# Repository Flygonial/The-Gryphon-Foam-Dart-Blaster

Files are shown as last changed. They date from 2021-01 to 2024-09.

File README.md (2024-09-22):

# The-Gryphon-Foam-Dart-Blaster
The Gryphon is a mostly 3D printable, hobby-grade, Nerf semi-automatic flywheel blaster. Its main design features are as follows:

* Uses 130 to 180 sized 20.4mm , brushed DC motors.
* Semi-auto by rack and pinion with 1:3 gear multiplication. The trigger pull is fairly short at 12mm.
* Accepts 33 to 38mm OD flywheels (all 2mm shaft fit, superstock upgrade flywheels).
* Utilizes a horizontal flywheel cage that bolts directly onto the magwell. This is a mounting pattern less prone to misalignment than a Stryfe's mounting bosses or similar.
* Accepts Worker Talon mags, Katana-geometry mags with a lower release cut-out, and almost all full-length magazines.
* Battery is located in the stock or a side battery tray.
* Full-length feed guide integrated in magwell for maximum feeding reliability.
* Bore-axis is almost as close as possible to top rail of blaster, which is theoretically more intuitive to aim with.
* Will fit on build volume as small as 120 mm<sup>3</sup>.

Some options/variable features are:

* Variable motor center distances from 43.5mm to 38.5mm (Eclipse).
* Full-length, flat-top picatinny rail.
* Ambidextrous, or one-sided sling mounts, or a WORKER attachable sling mount.
* A mag release meant to be actuated by the operator's off-hand, and one meant for the dominant hand's middle finger.
* Flash hider: Helps work around cover, and can be used to house and launch a mega dart.
* Kill-switch mount on stock, and a kill-switch + voltmeter mount on stock, and variations for imperial PVC using 3/4'' PVC instead of 25mm PVC.
* An additional EXPD stock option that holds larger batteries, has the same options.
* 14mm or 14.5mm bore flywheel cages or MAX cages, which are 15mm bore, Daybreak / Twilight only, have extra motor can support, and are intended for maximum FPS.
* An optional foregrip and magwell option for mounting this foregrip.
* An optional bottom-picatinny variant of the motor cover.
* 2-stage flywheel cages in all the aforementioned 'crushes' and bore options.
* Talon, 'Kathanha/Katobu', and full-length magwell options.

Required for assembly:

* Two 130-180 sized motors.
* 33 to 38mm, 2mm shaft fit flywheels
* 16-18 AWG multi-strand hobby wire
* Connectors of choice (XT60, Deans, bullet connectors), and heat shrink.
* One full-sized microswitch, 15A or 21A.
* M3 nuts
* M3 screws: 5mm length, 8mm length, 10mm length, one 14-16mm length for mag release pivot, one 20mm length for one specific screw on the motor cover.
* M2 screws: 4-5mm length for motor mounting.
* 2x20mm steel dowel pin for the pinion gear.
* 0.5mm coil thickness, 5mm diameter compression springs. 15mm in length for the mag release, 50mm in length for the trigger return spring.
* An adhesive for stock assembly, preferably methyl methacrylate based.
* Modular connectors to flywheel cage and to stock assembly (if using kill switch and/or voltmeter) highly recommended.
* For a battery stock: 10-20cm length of 25mm OD PVC pipe (length depends on however long you want your stock), or 3/4' Sch 40 PVC.

# Licensed under the CC0 1.0 Universal Public Domain Dedication (Creative Commons) license.

Do whatever you please with this blaster, modify, distribute, sell. Preferably don't claim ownership of the original design, that'd be all I want.

The main CAD files are bigger than 25 MB and have stopped playing nice with GitHub, so the most up to date source files at any time are available here: https://a360.co/4bTqc8o

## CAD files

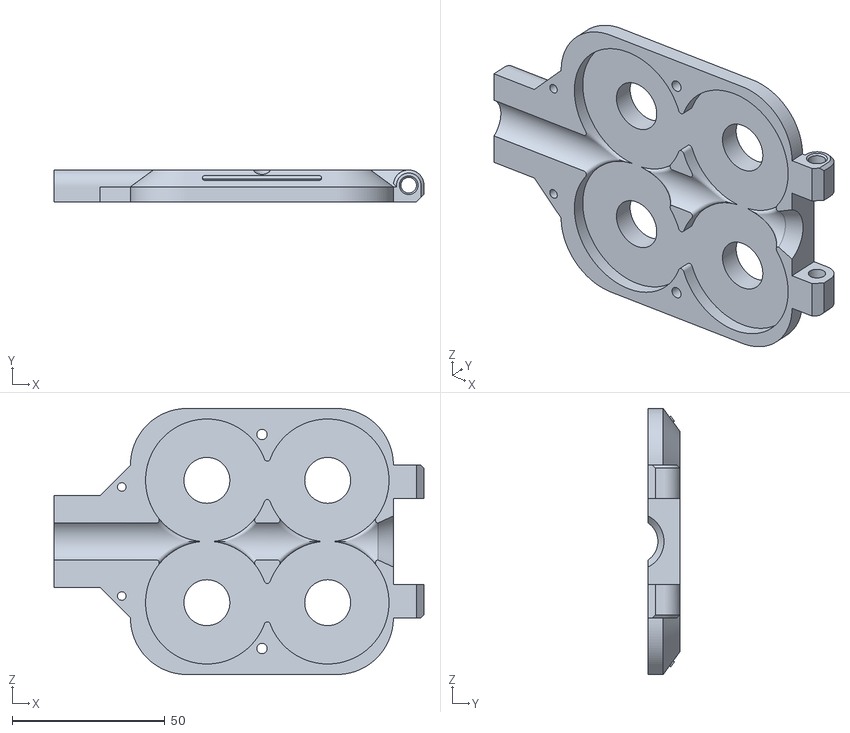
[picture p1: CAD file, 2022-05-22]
Gryphon Takedown/14.5mm Bore/2S 14.5mm Bore TKD/2S 40mm TKD (14.5)/2S 40mm FW Cover (14.5).stl
121.0 x 10.5 x 87.0

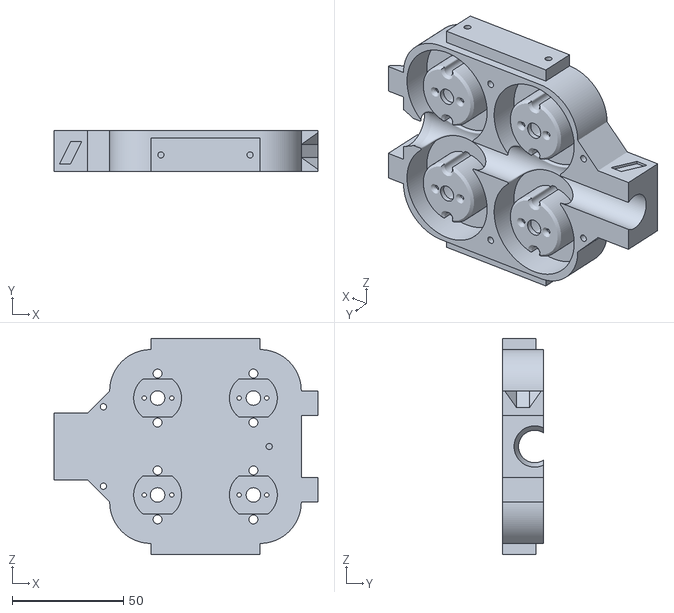
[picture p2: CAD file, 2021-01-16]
Gryphon Takedown/14.5mm Bore/2S 14.5mm Bore TKD/2S 43.5mm FWC TKD (14.5)/2S 43.5mm FWC TKD (14.5).stl
118.5 x 18.5 x 97.0

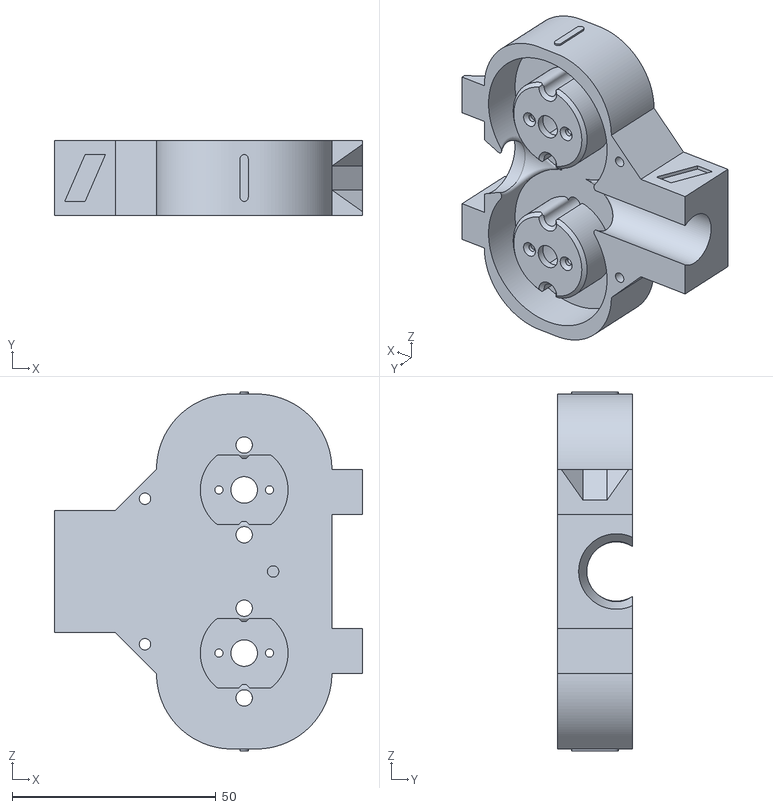
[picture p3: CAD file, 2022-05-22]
Gryphon Takedown/14.5mm Bore/40mm TKD (14.5)/40mm FWC TKD (14.5).stl
75.5 x 18.5 x 88.0

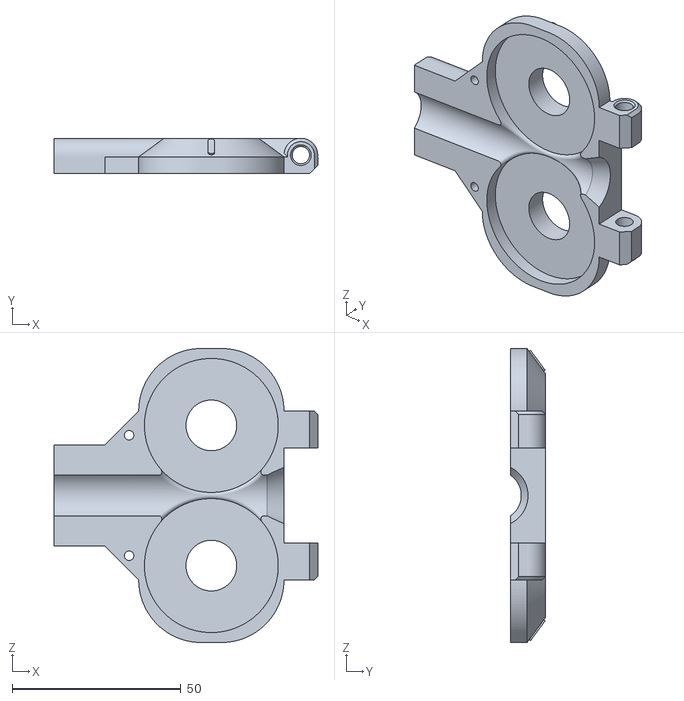
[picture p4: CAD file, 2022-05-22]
Gryphon Takedown/14.5mm Bore/41.5mm TKD (14.5)/41.5mm FW Cover TKD (14.5).stl
78.0 x 10.5 x 87.0

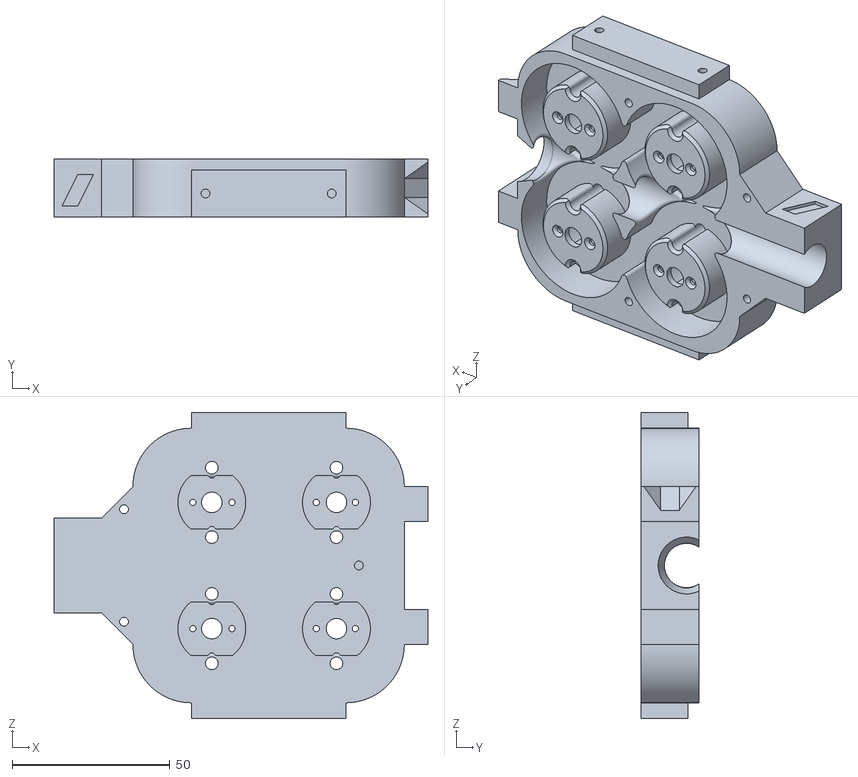
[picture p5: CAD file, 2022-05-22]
Gryphon Takedown/14mm Bore/2S 14mm Bore TKD/2S 40mm TKD/2S 40mm FWC TKD.stl
118.5 x 18.5 x 97.0

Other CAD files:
Gryphon Takedown/14.5mm Bore/2S 14.5mm Bore TKD/2S 41.5mm TKD (14.5)/2S 41.5mm FWC TKD (14.5).stl
Gryphon Takedown/14.5mm Bore/2S 14.5mm Bore TKD/2S 41mm TKD (14.5)/2S 41mm FW Cover TKD (14.5).stl
Gryphon Takedown/14.5mm Bore/2S 14.5mm Bore TKD/2S 42.5mm TKD (14.5)/2S 42.5mm FW Cover TKD (14.5).stl
Gryphon Takedown/14.5mm Bore/2S 14.5mm Bore TKD/2S 42mm TKD (14.5)/2S 42mm FW Cover TKD (14.5).stl
Gryphon Takedown/14.5mm Bore/2S 14.5mm Bore TKD/2S 43mm TKD (14.5)/2S 43mm FW Cover TKD (14.5).stl
Gryphon Takedown/14.5mm Bore/41mm TKD (14.5)/41mm FW Cover TKD (14.5).stl
Gryphon Takedown/14.5mm Bore/42.5mm TKD (14.5)/42.5mm FW Cover TKD (14.5).stl
Gryphon Takedown/14.5mm Bore/42mm TKD (14.5)/42mm FWC TKD (14.5).stl
Gryphon Takedown/14.5mm Bore/43.5mm TKD (14.5)/43.5mm FW Cover TKD (14.5).stl
Gryphon Takedown/14.5mm Bore/43mm TKD (14.5)/43mm FW Cover TKD (14.5).stl
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

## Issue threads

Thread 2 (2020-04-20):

.5x5x50mm compression springs

Lastcraft484, 2020-04-20:
Call me an idiot but I can not for the life of me find the 50mm compression spring for the trigger. I found the 15mm for the mag release and it works great. Is the spring the same length as a nerf blaster trigger? Any help to find one would be greatly appreciated.

SFPROXY, 2020-06-14:
Hi Lastcraft,

[This](https://www.aliexpress.com/item/33021841876.html) is the source I bought my springs. Hope it helps.

Thanks

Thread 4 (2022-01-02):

Print Orientations?

GalaxyCr8r, 2022-01-02:
I may be missing them - but the print orientations should at least be referenced in the readme...

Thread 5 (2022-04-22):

Picatinny dimensions

silvalis, 2022-04-22:
Could you please fix your picatinny rail dimensions? The max width is undersized by nearly 1.5mm.

Hayes4u2c, 2022-04-22:
I have no idea what you are talking about.

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

Flygonial, 2022-05-16:
Sorry for the late response, I'm not in the habit of frequently checking my notifications on GitHub. This is true, and it was deliberate. Some knock-off picatinny accessories intended to slide on (where the entire piece is unibody rather than having a part to clamp down with a bolt), are too tight of a fit on proper picatinny dimensions. Some examples include knock-off Magpul back-up sights that I've used before.

That was a decision made over three years ago, however, and I'm very willing to work on redimensioning the picatinny to actual spec and relegating the current, thinner rail to a secondary option in some hidden-away folder.

silvalis, 2022-05-17:
Might be worth seeing if anyone is against picatinny resize?
Nearly 1/2 of the rail devices I have (in the 10s of devices - optics, risers, lights, etc) can't be used on them, as the clamp is physically blocked from tightening that far down. A brief look at ali and I'd suggest that its more likely for a sight or riser to have issues, than to clamp correctly.

Flygonial, 2022-05-17:
Hmm good point, having designed it to accommodate for a few outliers probably excludes more attachments than it includes. Knowing that, I'll up the priority of this into next update. If anyone is against it, for whatever reason, the old files can always be kept around.

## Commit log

2019-04-22 Create STLs
    All STL files for the blaster's 3D printable components.
2019-05-02 Reuploading revised Stock Caps / Sling Mounts
    Updated 'Stock Cap' piece to be 5mm thick on the screw mounts to the back of the pusher mechanism from 2.5mm (this is a high stress piece if the stock smacks something, it should not have been that t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
    [Stock Cap (A).stl, Stock Cap (L).stl, Stock Cap (R).stl]
2019-05-02 Reuploading CAD files
    Reuploading source files to be up to date with updates to the stock cap and buttplate.
2019-05-02 Reuploading Tray Door / Buttplate
    Also altered the buttplate to have a more ergonomic depression to wrap around the operator's shoulder.
    [Tray Door : Buttplate.stl]
2019-05-11 Adding a split picatinny rail option
    Split the 252mm length picatinny rail to shorter sections that will fit on a 120x120mm plate.
    [Flat Top Picatinny Front.stl, Flat Top Picatinny Rear.stl]
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2019-05-18 Update README.md
    Added mention of dowel pin for the pinion gear.
2019-08-03 V1.1 STL files
    Includes fixes and little tidbits I forgot to include a long time ago, plus a big extra feature. This includes 3/4'' PVC compatible stocks, a trigger guard that is now fully chamfered where there were sharp edges, a Bobololo styled rev trigger. The big extra feature would be options for two-stage cages.
    [2S + 1S Picatinny Mesh.stl, 2S + HL Top Picatinny Front.stl, 2S + HL Top Picatinny Rear.stl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]
2019-09-28 V1.11 files (09/28/19)
    Added the Kathanha / Katobu magwell, actual Katanas cant fit thanks to the magwell mounting solution that was originally used, unfortunately. Up next will be full-length magwells, which might be a wh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
    [Extended Mag Release (Kathanha).stl, Kathanha or Katobu Magwell.stl]
2020-01-05 V1.12 Update
    I've actually had this done for a while. Added an extra motor cover option for a single-stage cage that can accept a lower rail and has the same lower appearance as the dual-stage cage.
    [Motor Cover (Bottom Picatinny).stl]
2020-01-05 V1.12 CAD Files
    Includes other parts that are in development
2020-01-27 V1.13 Updates
    A biggie here in terms of compatibility here back: I've redesigned the flywheel cage to allow it to be printed in the opposite of the original orientation: with the side that the motors insert into as the bottom layer. Less supports (though still recommended), and hopefully less alignment issues with warping and other print defects. This required making the cage 1.5mm thicker (and in order to minimize this extension, I reduced the bottom clearance for the flywheels by 1mm (don't worry, it was initially deliberately excessive), and the mounting points were moved up 2mm. Therefore, the magwell is also now slightly different, and so are all motor cover designs. A new page has been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
    [2S 38.5mm FW Cover.stl, 2S 38.5mm FWC.stl, 2S 40mm FW Cover.stl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]
2020-01-27 V1.13 Update
    A side note: yes, the flash hider was changed as a result of the cage change.
    [Flash Hider.stl]
2020-02-08 Replacing old Motor Cover (Bottom Picatinny)
    Error in CAD where I forgot to include the Flash Hider thread hole
    [Motor Cover (Bottom Picatinny).stl]
2020-02-08 V1.2 Update
    The next big-ish update as it includes a feature I've put off working on and testing since I completed the blaster: a full-length magwell. A new foregrip for that magwell comes with it, all picatinny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
    [2S + FL Top Picatinny (Front).stl, 2S + FL Top Picatinny (Mid).stl, 2S + FL Top Picatinny (Rear).stl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]
2020-02-11 V1.2 Update Hotfix
    Forgot to upload this
    [Wire Run (FL).stl]
2020-04-17 Renamed files for NTFS compatibility
    [Battery Stock (3_4'' PVC).stl, Battery Stock (KS + VM) (3_4'').stl, Battery Stock (KS) (3_4'' PVC).stl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]
2020-06-11 V1.21 STL Files
    This is a large update and one of the final ones. The new 'EXPD Battery Stock' is available in metric, imperial, kill switch and voltmeter variants, and has volume for up to 110x36x31mm packs (though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
    [2S 40mm FW Cover (14.5).stl, 2S 40mm FWC (14.5).stl, 2S 41.5mm FW Cover (14.5).stl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]
2020-06-11 V1.21 Updates
    CAD files for the blaster as of this point
2020-06-11 Additional detail
    Changed outdated details such as the imperial stock material and that 14.5mm bore cages are an option
2020-07-08 V1.21 Fixes
    Unknown to me at first, some timeline changes caused the extrude for the flash hider threads on the 14.5mm bore flywheel covers to be broken. This has been fixed.
    [40mm FW Cover (14.5).stl, 41.5mm FW Cover (14.5).stl, 41mm FW Cover (14.5).stl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]
2020-07-08 V1.21 Fixes
    Files with the fixed flash hider mounts (to flywheel cover for 14.5mm cages) in CAD, including also hidden changes to the 'FPS dropper' attachment. It still is not in the STL files as I don't deem it fit, but it's there and some people seem to have gotten nicer groupings out of it.
2021-01-16 Gryphon Takedown STL files
    All .stl file options for the takedown Gryphon variant that replace the original components.
    [2S 38.5mm FW Cover TKD.stl, 2S 38.5mm FWC TKD.stl, 2S 40mm FW Cover TKD.stl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]
2021-01-16 Adding Gryphon Takedown files
    Uploading all .stl files in the takedown variant of the Gryphon that replace the original components.
    [2S 38.5mm FW Cover TKD.stl, 2S 38.5mm FWC TKD.stl, 2S 40mm FW Cover TKD.stl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]
2021-03-07 V1.22 Updates for TKD:
    The takedown variants of the MAX cages for single-stage.
    [39.5mm FW Cover TKD MAX.stl, 39.5mm FWC TKD MAX.stl]
2021-03-07 V1.22 Update (03/07/21):
    Developed MAX cages for single-stage variants. These are 15mm bore (essentially eliminating barrel drag), 39.5mm center-distance cages for Daybreak / Twilight wheels. As Eclipse wheels are not anywhere near available, this is a quick variant for maximizing FPS out of a single-stage. These have not been sorted into the ZIP yet until I get access to a Mac to fix the issues with ":" in the file names for x86 with the EXPD stocks. Bless for the pull request and again, sorry for taking so long to get to it.
    [39.5mm FW Cover MAX.stl, 39.5mm FWC MAX.stl]
2021-03-28 V1.23 Update:
    An update where the single-stage MAX cages have additional ridges added in the motor well to improve rigidity and possibly durability against the forces induced by high crush, and dual-stage MAX cage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
    [39.5mm FWC MAX.stl]
2021-03-28 V1.23 Update (03/27/21):
    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
    [2S 40-39.5mm FW Cover MAX.stl, 2S 40-39.5mm FWC MAX.stl]
2021-03-28 V1.23 Update for TKD (03/27/21):
    MAX TKD single-stage cages also have reinforcement ridges added to the motor wells. Also included are the dual-stage TKD variants for the MAX have also been added for compatibility's sake.
    [39.5mm FWC MAX TKD.stl]
2021-03-28 V1.23 Updates (3/27/21):
    An update where the single-stage MAX cages have additional ridges added in the motor well to improve rigidity and possibly durability against the forces induced by high crush, and dual-stage MAX cages have been added. These are 40mm into a second 39.5mm stage cages intended for Daybreak / Twilight wheels, possess a 15mm bore to almost eliminate barrel drag, and should hit 240 FPS give or take. Furthermore, NTFS compatibility with stock variants has been fixed for good with the EXPD variants also fixed.
    [EXPD Battery Stock (Imperial).stl, EXPD Battery Stock (KS + VM) (Imperial).stl, EXPD Battery Stock (KS + VML) (Imperial).stl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]
2021-03-28 Deleting Redundant Gryphon Takedown Files
    [2S 38.5mm FW Cover TKD.stl, 2S 38.5mm FWC TKD.stl, 2S 40mm FW Cover TKD.stl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]
2021-03-28 V1.23 Updates (03/27/21):
    An update where the single-stage MAX cages have additional ridges added in the motor well to improve rigidity and possibly durability against the forces induced by high crush, and dual-stage MAX cages have been added. These are 40mm into a second 39.5mm stage cages intended for Daybreak / Twilight wheels, possess a 15mm bore to almost eliminate barrel drag, and should hit 240 FPS give or take. Furthermore, NTFS compatibility with stock variants has been fixed for good with the EXPD variants also fixed, and the regular stock Imperial variants being renamed.
    [Battery Stock (Imperial).stl, Battery Stock (KS + VM) (Imperial).stl, Battery Stock (KS) (Imperial).stl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]
2021-04-02 V1.23 Update: 2S TKD MAX
    The dual-stage TKD variants for the MAX have also been added for compatibility's sake, but I forgot them when I uploaded them.
    [2S 40-39.5mm FW Cover MAX TKD.stl, 2S 40-39.5mm FWC MAX.stl]
2021-04-04 V1.23 Replacement
    For whatever reason, the old cage was not the new one and I am unsure where to trace this as the files I had locally were correct.
    [2S 40-39.5mm FWC MAX TKD.stl]
2021-04-13 V1.23 Deletions:
    Deleted the redundant files that were accidentally not replaced in the STLs as the new, NTFS compatible ones were added.
    [EXPD Battery Stock (KS) (3:4' PVC).stl]
2021-04-13 V1.23 Deletions:
    Replaced the renamed files from pull request as they are now redundant with the naming scheme of putting (Imperial) after the file name. Of course, note that all PVC in Imperial is meant for 3/4 inch Sch 40 PVC.
    [Stock Cap (R) (3_4'' PVC).stl]
2021-05-01 V1.24 (05/01/21):
    Added a side battery tray design to the files. This is something that's been developed over a few different remixes by different people, but I either didn't like the appearance of many of them, the implementation of the tray door, or the lack of space offered in most of those designs. The internal volume of the tray is about 110x35x24mm (you will of course, need to slightly undersize), it uses a captive M3 nut and thumbscrew + latch for tool-less opening, and has a sling mount on the side that replaces the stock cap.
    [Side Battery Tray (L).stl, Side Battery Tray (R).stl, Side Tray Door (L).stl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]
2021-05-01 V1.24 CAD Files (05/01/21):
    Updated CAD files for the V1.24 update, the default visibility of objects has changed that said.
2021-05-01 V1.24 Update (05/01/21):
    Added a side battery tray design to the files. This is something that's been developed over a few different remixes by different people, but I either didn't like the appearance of many of them, the implementation of the tray door, or the lack of space offered in most of those designs. The internal volume of the tray is about 110x35x24mm (you will of course, need to slightly undersize), it uses a captive M3 nut and thumbscrew + latch for tool-less opening, and has a sling mount on the side that replaces the stock cap. A tray that occupies the right hand side is also available.
    On a tangential note, the rev triggers have been updated to be more ergonomic.
    [Bobo Rev Body.stl, Bobo Rev Face.stl, Rev Trigger.stl]
2021-05-30 V1.25 Update (05/30/21)
    Altered the side battery tray design file: I wasn't happy with a lot of the first iteration. Firstly, I simplified the design to not require one to remove the top mech cover to install. Then, I added a mm of extra space in the dimension of a pack's width as I've found that the wire leads from a pack often add extra width or prevent fit. Finally, I created various tray door options ranging from a low-profile to an extended variant (for packs which take up all of the tray space and it can be impossible to fit an XT60 in the remaining space), and a low-profile variant with a cut-out should you want the low profile but not mind having dangling wires.
    [Side Battery Tray (L).stl, Side Battery Tray (R).stl, Side Tray Door (L).stl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]
2022-05-16 V1.3 Accessories Update:
    Part of the V1.3 update which primarily involves a fundamental restructuring of the pusher mech/magwell assembly. The mech covers have been merged into one piece and redesigned to print in such a way and retain space for wiring and guiding the pusher. The grip frame has been modified to be merged with a wider magwell joint, which should hopefully be more structurally sound in addition to reducing the part and hardware count. The Mech Cover to Grip attachment and Magwell to Grip Frame attachment points have been redesigned to accept M3x25 screws and an M3 hex nut to further drop hardware requirements. This cumulatively drops the part count by 3 and the screw count by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
    [1S FWC Picatinny.stl, 2S FWC Picatinny.stl, FL Magwell Picatinny.stl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]
2022-05-16 V1.3 Battery Stock Changes
    Part of the V1.3 update which primarily involves a fundamental restructuring of the pusher mech/magwell assembly. The mech covers have been merged into one piece and redesigned to print in such a way and retain space for wiring and guiding the pusher. The grip frame has been modified to be merged with a wider magwell joint, which should hopefully be more structurally sound in addition to reducing the part and hardware count. The Mech Cover to Grip attachment and Magwell to Grip Frame attachment points have been redesigned to accept M3x25 screws and an M3 hex nut to further drop hardware requirements. This cumulatively drops the part count by 3 and the screw count b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
    [Battery Stock (Imperial).stl, Battery Stock (KS + VM) (Imperial).stl, Battery Stock (KS + VM).stl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]
2022-05-16 V1.3 Deletion
    This operation was performed (and it's hacky and likely bad practice) as the arrangement of the flywheel cage directory was reorganized to not require one to go as deep for some options (ie: 14.5mm b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
    [2S + 1S Picatinny Mesh.stl, 2S + FL Top Picatinny (Front).stl, 2S + FL Top Picatinny (Mid).stl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]
2022-05-16 V1.3 FWC Reupload/Changes
    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
    [1S 39.5mm FW Cover MAX.stl, 1S 39.5mm FWC MAX.stl, 2S + 1S Picatinny Mesh.stl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]
2022-05-16 V1.3 Grip Changes
    Part of the V1.3 update which primarily involves a fundamental restructuring of the pusher mech/magwell assembly. The mech covers have been merged into one piece and redesigned to print in such a way and retain space for wiring and guiding the pusher. The grip frame has been modified to be merged with a wider magwell joint, which should hopefully be more structurally sound in addition to reducing the part and hardware count. The Mech Cover to Grip attachment and Magwell to Grip Frame attachment points have been redesigned to accept M3x25 screws and an M3 hex nut to further drop hardware requirements. This cumulatively drops the part count by 3 and the screw count by 8.
    A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
    [Bobo Rev Body.stl, Bobo Rev Face.stl, Grip Frame.stl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]
2022-05-16 V1.3 Full-Length Magwell Changes
    Part of the V1.3 update which primarily involves a fundamental restructuring of the pusher mech/magwell assembly. The mech covers have been merged into one piece and redesigned to print in such a way and retain space for wiring and guiding the pusher. The grip frame has been modified to be merged with a wider magwell joint, which should hopefully be more structurally sound in addition to reducing the part and hardware count. The Mech Cover to Grip attachment and Magwell to Grip Frame attachment points have been redesigned to accept M3x25 screws and an M3 hex nut to further drop hardware requirements. This cumulatively drops the part count by 3 and the screw c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
    [FL Magwell (Grip).stl, FL Magwell.stl]
2022-05-16 V1.3 Half-Length Magwell changes
    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
    [Kathanha Magwell (Grip).stl, Kathanha Magwell.stl, Magwell (Grip).stl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]
2022-05-16 Moved Trigger Rack to Pusher Mechanism Folder
    It isn't organized this way in the Fusion file but this makes more logical sense.
    [Trigger Rack.stl]
2022-05-16 V1.3 Pusher Mechanism Updates
    Part of the V1.3 update which primarily involves a fundamental restructuring of the pusher mech/magwell assembly. The mech covers have been merged into one piece and redesigned to print in such a way and retain space for wiring and guiding the pusher. The grip frame has been modified to be merged with a wider magwell joint, which should hopefully be more structurally sound in addition to reducing the part and hardware count. The Mech Cover to Grip attachment and Magwell to Grip Frame attachment points have been redesigned to accept M3x25 screws and an M3 hex nut to further drop hardware requirements. This cumulatively drops the part count by 3 and the screw coun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
    [Mech Cover.stl, Trigger Rack.stl]
2022-05-17 V1.3: Mech Cover Hotfix
    Forgot a screw hole mount for the side battery tray that was forgotten about amidst the flurry of development. This replaces and fixes that.
    [Mech Cover.stl]
2022-05-17 V1.3: 42.5mm FWC (14.5) Hotfix
    Thanks to /u/theboyrossy for pointing this blunder out! Originally both files were the flywheel cover, replaced the cage with the actual cage.
    [42.5mm FWC (14.5).stl]
2022-05-19 Added Default Stock (renamed)
    [Battery Stock (KS + VM).stl, Battery Stock (KS).stl, Battery Stock.stl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]
2022-05-19 V1.3 Hotfix: Missing Lock Release and Locking Pin
    These items were missing from the buffer battery tube directory
    [Battery Stock (Imperial).stl, Battery Stock (KS + VM) (Imperial).stl, Battery Stock (KS + VM).stl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]
2022-05-22 Deleted Gryphon Takedown for V1.3 Replacement
    [2S 38.5mm FW Cover TKD.stl, 2S 38.5mm FWC TKD.stl, 2S 40-39.5mm FW Cover MAX TKD.stl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]
2022-05-22 Partial Upload of V1.3 Takedown files
    V1.3 co-update (05/22/22): The blaster has been brought up to date with the past few updates in V1.2 and now up to V1.3 standards, with a few additional minor tweaks. The pusher mech cover has been merged, the magwell joint has been merged with the grip, the stock mounting points have been changed to give them significantly more strength, and the magwell mounting points have been moved for the same reason with respect to the magwell joint. There's new EXPD wire run option for half-length magwells that should allow for longer runs of wires to better fit (which also ensures an easier swap to a full-length magwell). Finally, flywheel cages between 41.5mm an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
    [2S 40-39.5mm FW Cover MAX.stl, 2S 40-39.5mm FWC MAX.stl, 2S Bottom Picatinny TKD.stl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]
2022-05-22 V1.3 Takedown FWC Uploads
    There were already over 100 files (mainly FWC variations) so this was split into two commits.
    V1.3 co-update (05/22/22): The blaster has been brought up to date with the past few updates in V1.2 and now up to V1.3 standards, with a few additional minor tweaks. The pusher mech cover has been m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
    [2S 38.5mm FW Cover TKD.stl, 2S 38.5mm FWC TKD.stl, 2S 40mm FW Cover (14.5).stl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]
2022-05-22 V1.3 Pusher TKD
    As the reinforced pusher mech to stock mounts interfere with the old pusher design, a bit of the end has been chamfered to fit. Should align closely and help with assembly as well.
    [Pusher TKD.stl]
2022-08-07 V1.31 Update: Mech Cover
    Removed hold-down geometry on the wire channels in the mech cover: wires can now just be slotted over instead of needing to be threaded through. I decided that with appropriate lubrication and thick enough wire cut to an appropriate length, there shouldn't be much issue with the pusher mech binding up.
    [Mech Cover.stl]
2022-08-07 V1.31 Update: Revised buffer tube design
    The buffer tube was changed to print with the top of the tube as the bottom layer. In order to cover the top mount of the stock, an extra piece with the sling mount has been added (as the new print orientation would also weaken the sling mount if it couldn't be printed in a different orientation). This should reduce print complexity and eliminate the need to reinforce the buffer tube.
    [Buffer Tube Top Mount.stl, Buffer Tube V1.31.stl]
2023-03-14 V1.31 Addendum:
    Some people have had trouble with the mech cover piece and the revisions I made, so I made the previous piece a secondary version and the new piece has one ‘hold-down’ section within to keep wires se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
    [Mech Cover.stl]
